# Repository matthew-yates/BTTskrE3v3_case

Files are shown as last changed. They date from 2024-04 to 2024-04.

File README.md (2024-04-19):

These are OpenSCAD design files that can be used for 3D printing a stand alone case for a 3D printer control board (SKR mini E3 V3) and LCD control panel (TFT35 E3 V3).  The control board and LCD panel specs can be found from the manufacturer, Bigtreetech:

http://bttwiki.com/SKR%20MINI%20E3.html

https://bttwiki.com/TFT35%20E3.html

After assembly and programming the microcontroller with Marlin firmware, this case provides a stand alone unit for controlling a 3D printer or CNC machine.

Key features of the case:

* opening for wires required to connect an external power supply, stepper motors, a bed heater, and other optional components on a 3D printer or CNC machine.
* slot to access micro SD card reader used for programming the microcontroller.
* opening for micro USB port that can be used for external control over serial communication from an attached computer.
* slot for accessing the standard SD card and USB-A port that allows control using g-code files.
* mounting points for two 40 mm fans for ventilation.

The image below is a rendering of the bottom part of the case. The "mouse ears" on the box corners aid in keeping the box corners from lifting during printing. The mouse ears can be cut off after printing.

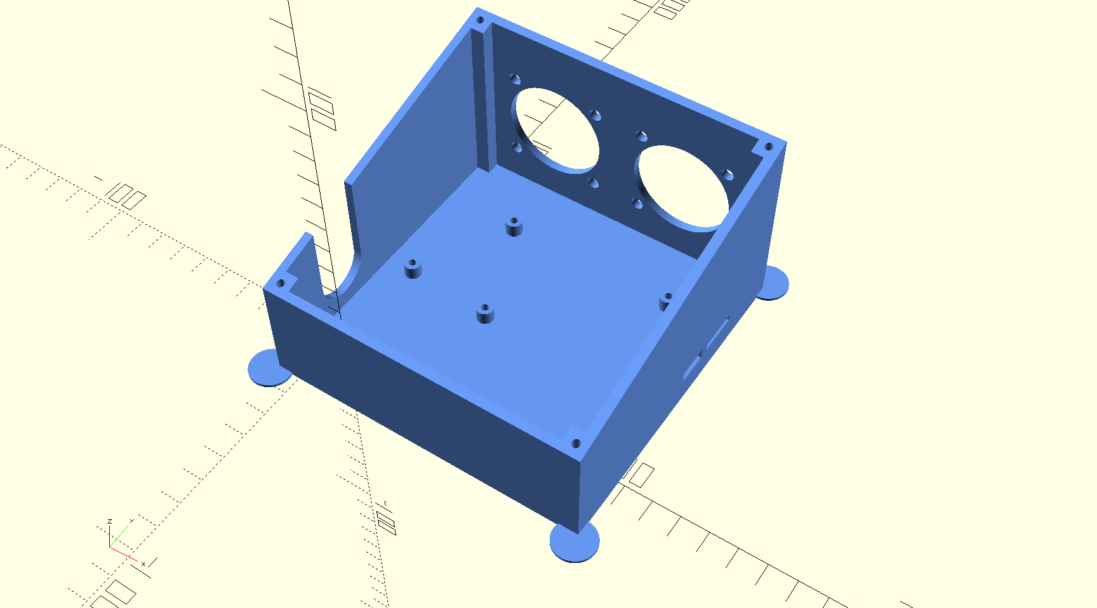
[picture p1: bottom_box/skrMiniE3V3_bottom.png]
bottom box


The image below is a rendering of the top box portion of the case. In addition to the "mouse ears" on the corner to aid in printing, there are thin rectangular supports on each of the four corners that aid in 3D printing.  The mouse ears and supports can be cut off the part after printing.

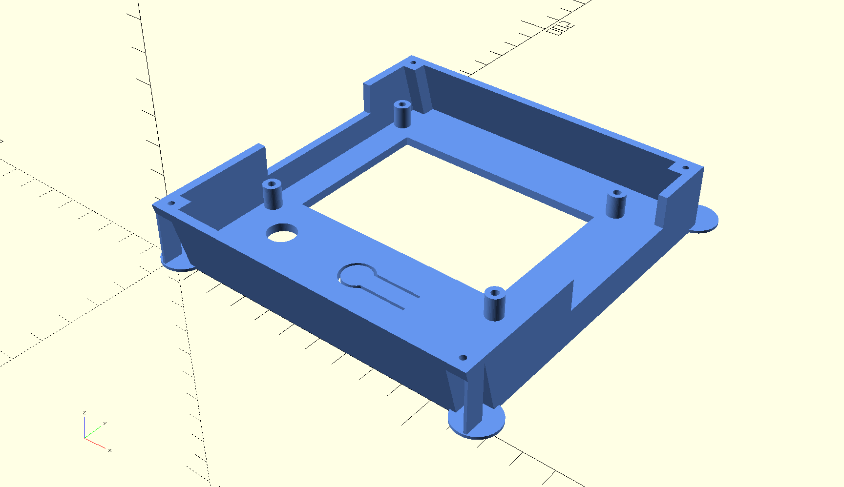
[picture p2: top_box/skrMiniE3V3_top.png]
top box


The image below is a rendering of an exploded view of the completed case after removing printer supports, mounting the TFT35 E3 V3 board to the top portion of the case, and mounting the SKR Mini E3 V3 board to the bottom portion of the case.  The case is colored blue and the Bigtreetech components are colored gray.

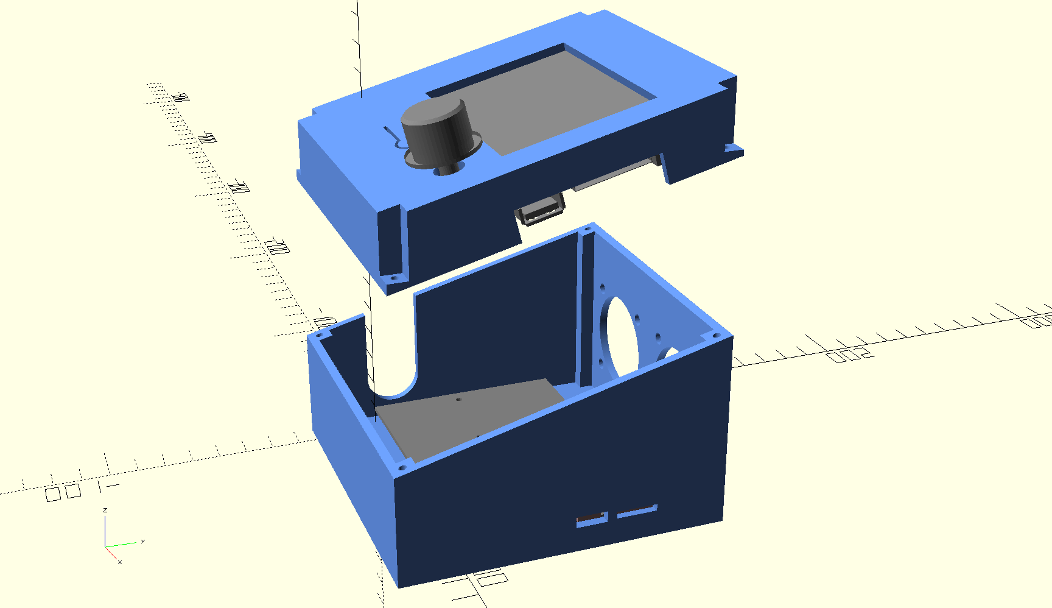
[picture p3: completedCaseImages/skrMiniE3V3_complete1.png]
complete case exploded


The image below is a rendering of the completed case after assembly.  The top part of the case is mounted to the bottom part using M3 screws 8 mm in length.

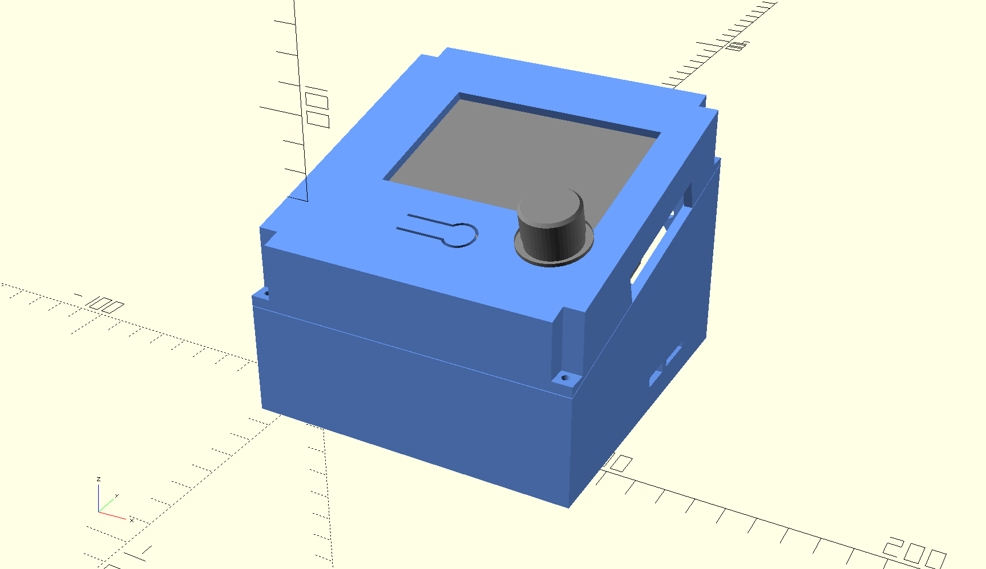
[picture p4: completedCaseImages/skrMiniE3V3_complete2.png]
complete case assembled


For assembly:

* remove printing supports and mouse ears from corners using a sharp blade.
* ream open the four mounting holes on the corners of the top part of the case to allow an M3 screw to pass through.  A 1/8 inch drill bit can be used.
* PCB stand offs as well as the bottom part of the case are printed with holes that allow normal M3 screws to be used (self tapping screws are not needed).
* M3 screws with a pitch of 0.5 mm and length of 8 mm can be used for all PCB mounting holes.
* 40 mm fans must be selected that operate on the same voltage as the external DC power supply.  For most 3D printers, this is 24 Volts.

Below is a photograph of the assembled case with the fans and circuit boards mounted inside:

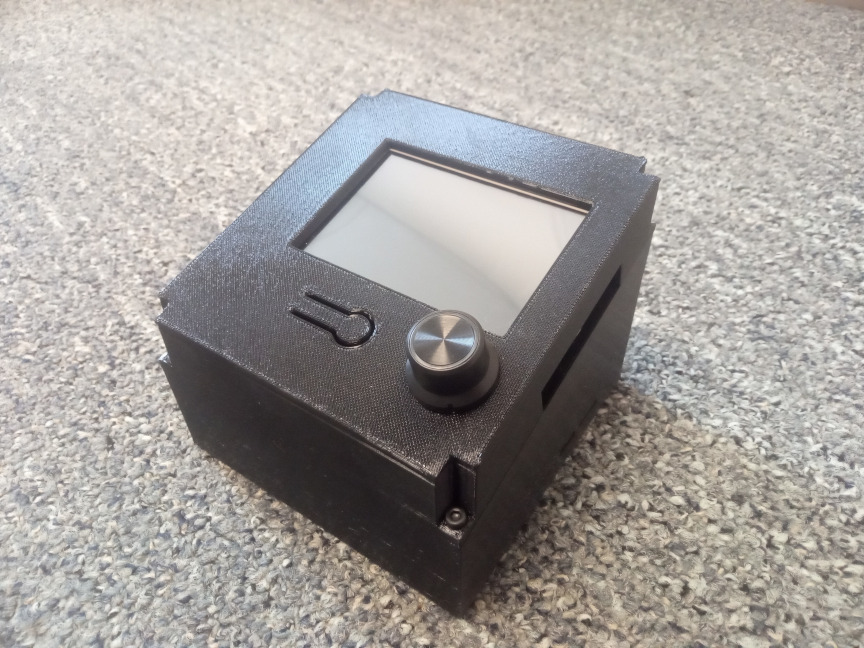
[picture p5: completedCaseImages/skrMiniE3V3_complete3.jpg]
complete case photo


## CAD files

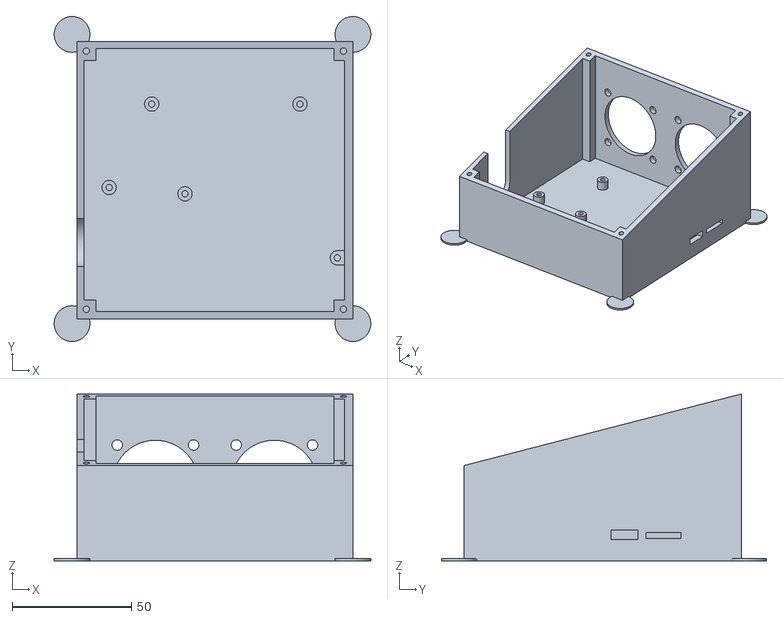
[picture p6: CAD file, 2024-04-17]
bottom_box/skrMiniE3V3_bottom.stl
132.8 x 136.2 x 70.0

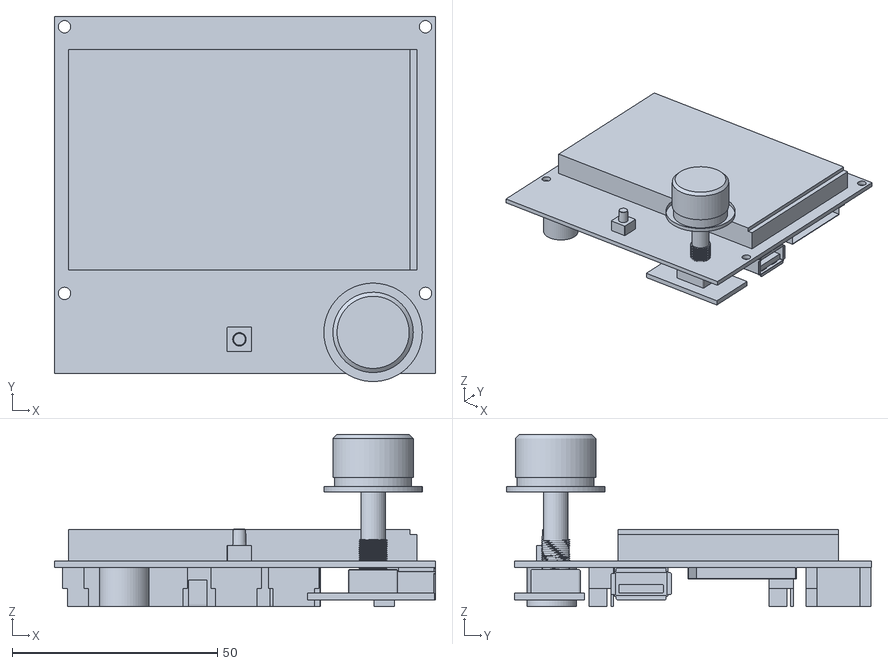
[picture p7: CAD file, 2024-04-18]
top_box/tft35model.stl
93.0 x 89.0 x 42.0

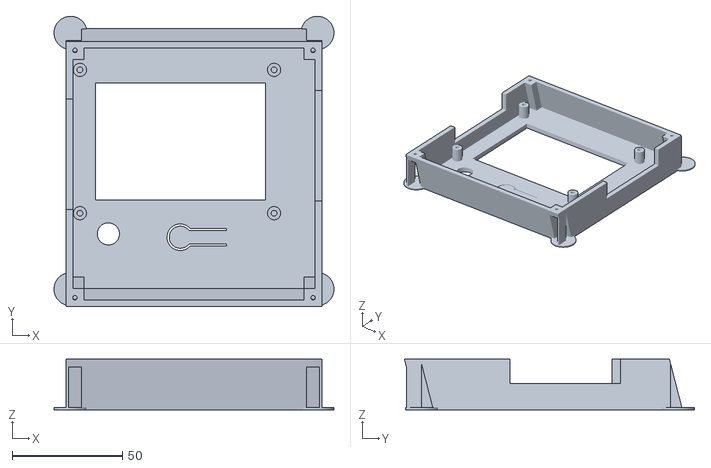
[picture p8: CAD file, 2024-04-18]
top_box/skrMiniE3V3_top.stl
126.8 x 131.4 x 23.0

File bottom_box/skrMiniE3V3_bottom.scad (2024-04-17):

$fa = 1.0;
$fs = 0.4;
// PCB dimensions  ****comment out before generating STL****
// gray is main board with screw hole cut outs
//color("gray"){
//    translate([0,0,8])
//    difference(){
//        cube([103.75,70.25,1.6]);
//        translate([5.54,32.05,-1]) cylinder(h=3,r=1.3);
//        translate([37.34,29.41,-1]) cylinder(h=3,r=1.3);
//        translate([101.22,2.56,-1]) cylinder(h=3,r=1.3);
//        translate([85.55,67.03,-1]) cylinder(h=3,r=1.3);
//        translate([23.40,67.03,-1]) cylinder(h=3,r=1.3);}}
// rosybrown color for surface mount parts on PCB
//color("rosybrown"){
//    // approx shape of SD card reader
//    translate([93.7,53.76,9.6]) cube([11.55,13.7,2]);
//    // approx shape of micro USB port
//    translate([99.5,40,9.6]) cube([5.75,8.38,2]);}
//
//******comment out code above before generating STL********
//
color("cornflowerblue"){
// translate box to leave gaps around PCB
// 5 mm left
// 20 mm front and back
// 0.5 mm right
//
difference(){
//Main box
union(){
   difference(){
        translate([-8,-23,0]) cube([115.75,116.25,70]);
        translate([-5,-20,3]) cube([109.25,110.25,70]);}
    // add corner supports
    translate([-5,-20,0])
    cube([5,5,70]);
    translate([-5,85.25,0])
    cube([5,5,70]);
    translate([99.75,-20,0])
    cube([5,5,70]);
    translate([99.75,85.25,0])
    cube([5,5,70]);
    // add PCB standoffs
    translate([5.54,32.05,0]) cylinder(h=8,r=3);
    translate([37.34,29.41,0]) cylinder(h=8,r=3);
    translate([85.55,67.03,0]) cylinder(h=8,r=3);
    translate([23.40,67.03,0]) cylinder(h=8,r=3);
        hull(){
        translate([101.22,2.56,0]) cylinder(h=8,r=3);
        translate([104,-0.44,0]) cube([2,6,8]);}
    }
 // box cut outs
 //
    // PCB mounting holes for M3 screws
    translate([5.54,32.05,3]) cylinder(h=6,r=1.35);
    translate([37.34,29.41,3]) cylinder(h=6,r=1.35);
    translate([101.22,2.56,3]) cylinder(h=6,r=1.35);
    translate([85.55,67.03,3]) cylinder(h=6,r=1.35);
    translate([23.40,67.03,3]) cylinder(h=6,r=1.35);
    // top lid mounting holes for M3 screws
    translate([-4,-19,32]) cylinder(h=10,r=1.35);
    translate([-4,89.25,61]) cylinder(h=10,r=1.35);
    translate([103.75,-19,32]) cylinder(h=10,r=1.35);
    translate([103.75,89.25,61]) cylinder(h=10,r=1.35);
    // opening for wires
    translate([-7,9,19])
    hull(){
        translate([0,0,35]) cube([5,20,5],center=true);
        rotate([0,90,0])
        cylinder(h=5,r=10,center=true);}
    // cut out for SD card slot
    translate([103.25,53.26,9.5]) cube([5,14.7,2.5]);
    // cut out for micro SD cable
    translate([103.25,38.5,9]) cube([5,11.38,4]);
    // holes for two 40 mm fans
        // large holes for air flow
        // fan 1
    translate([24.94,94.25,32.6]) rotate([90,0,0]) cylinder(h=5,r=18);
        // fan 2
    translate([74.82,94.25,32.6]) rotate([90,0,0]) cylinder(h=5,r=18);
        // small holes for fan 1 screws
    translate([8.94,94.25,48.6]) rotate([90,0,0]) cylinder(h=5,r=2.2);
    translate([40.94,94.25,48.6]) rotate([90,0,0]) cylinder(h=5,r=2.2);
    translate([40.94,94.25,16.6]) rotate([90,0,0]) cylinder(h=5,r=2.2);
    translate([8.94,94.25,16.6]) rotate([90,0,0]) cylinder(h=5,r=2.2);
        // small holes for fan 2 screws
    translate([90.82,94.25,48.6]) rotate([90,0,0]) cylinder(h=5,r=2.2);
    translate([90.82,94.25,16.6]) rotate([90,0,0]) cylinder(h=5,r=2.2);
    translate([58.82,94.25,48.6]) rotate([90,0,0]) cylinder(h=5,r=2.2);
    translate([58.82,94.25,16.6]) rotate([90,0,0]) cylinder(h=5,r=2.2);
    // Top is angled at 14.47 deegrees.  This gives y-axis length 120 mm for lid.
    translate([-8.1,-23.1,40]) rotate([14.47,0,0]) cube([116.75,120.25,70]);
}
// add mouse ears for printing
translate([-10,-25,0]) cylinder(h=1,r=7.5);
translate([107.75,-25,0]) cylinder(h=1,r=7.5);
translate([107.75,96.25,0]) cylinder(h=1,r=7.5);
translate([-10,96.25,0]) cylinder(h=1,r=7.5);}

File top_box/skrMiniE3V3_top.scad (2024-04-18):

$fa = 1.0;
$fs = 0.4;
// PCB dimensions  ****comment out before generating STL****
//color("gray"){
//translate([175.1,-45.6,22.1]) rotate([0,180,0]) import("tft35model.stl");}
//******comment out code above before generating STL********
//
color("cornflowerblue"){
difference(){
union(){
//main plate
cube([115.75,120,3]);
// PCB standoffs
translate([6.23,36.37,0]) cylinder(h=11,r=3);
translate([6.23,101.27,0]) cylinder(h=11,r=3);
translate([94.13,101.27,0]) cylinder(h=11,r=3);
translate([94.13,36.37,0]) cylinder(h=11,r=3);
// left and right sides
translate([0,-5,3]) cube([3,125,20]);
translate([112.75,-5,3]) cube([3,125,20]);
// front and back angled to match bottom box
rotate([14.47,0,0]) cube([115.75,3,25]);
translate([0,117,0]) rotate([14.47,0,0]) cube([115.75,3,25]);
// corner supports and opening for screw tabs
rotate([14.47,0,0]) cube([8,8,25]);
translate([107.75,0,0]) rotate([14.47,0,0]) cube([8,8,25]);
translate([107.75,112,0]) rotate([14.47,0,0]) cube([8,8,25]);
translate([0,112,0]) rotate([14.47,0,0]) cube([8,8,25]);
}
//cut out for LCD panel
translate([13.18,42.32,-1]) cube([77,53,6]);
// holes for M3 PCB mounting screws
translate([6.23,36.37,3]) cylinder(h=9,r=1.35);
translate([6.23,101.27,3]) cylinder(h=9,r=1.35);
translate([94.13,101.27,3]) cylinder(h=9,r=1.35);
translate([94.13,36.37,3]) cylinder(h=9,r=1.35);
// flexible tab for reset button
difference(){
    union(){
        translate([51.67,25.5,-1]) cylinder(h=5,r=6);
        translate([51.67,21.5,-1]) cube([21,8,5]);}
translate([51.67,22.5,-2]) cube([25,6,7]);
translate([51.67,25.5,-2]) cylinder(h=7,r=5);
}
// cut out for knob
translate([19.12,27,-1]) cylinder(h=5,r=5);
// cut out for usb/SD card and venting
translate([-1,38,12]) cube([5,50,23]);
// cut out for venting
translate([111.75,42,12]) cube([5,50,23]);
// cut tabs off front
rotate([14.47,0,0]) translate([-1,-5,0]) cube([117.75,5,25]);
// cut tabs off back
translate([-1,120,0])rotate([14.47,0,0]) cube([117.75,7,25]);
// cut tabs off top
translate([-1,-10,23])  cube([117.75,140,5]);
// cut out for shorter M3 screws
rotate([14.47,0,0]) translate([-1,-1.,-3]) cube([8,8,23]);
rotate([14.47,0,0]) translate([108.75,-1.,-3]) cube([8,8,23]);
translate([108.75,113.,0]) rotate([14.47,0,0]) translate([0,0,-3]) cube([8,8,23]);
translate([-1,113,0]) rotate([14.47,0,0]) translate([0,0,-3]) cube([8,8,23]);
// M3 screw holes for mounting to bottom box
translate([4,4,0]) rotate([14.47,0,0]) translate([0,0,19])  cylinder(5,1.7);
translate([111.75,4,0]) rotate([14.47,0,0]) translate([0,0,19])  cylinder(5,1.7);
translate([4,116,0]) rotate([14.47,0,0]) translate([0,0,19])  cylinder(5,1.7);
translate([111.75,116,0]) rotate([14.47,0,0]) translate([0,0,19])  cylinder(5,1.7);
}
// add corner supports for printing
translate([0,-4.997,0]) cube([1,6.778,22.3]);
translate([114.75,-4.997,0]) cube([1,6.778,22.3]);
translate([0,107.8,0]) cube([1,6.778,21.1]);
translate([114.75,107.8,0]) cube([1,6.778,21.1]);
// add mouse ears for printing
translate([2,2,0]) cylinder(h=1,r=7.5);
translate([113.75,2,0]) cylinder(h=1,r=7.5);
translate([113.75,118,0]) cylinder(h=1,r=7.5);
translate([2,118,0]) cylinder(h=1,r=7.5);
}

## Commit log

2024-04-17 Update skrMiniE3V3_bottom.scad
    Added mouse ears to help hold down box corners while printing.
    [skrMiniE3V3_bottom.scad]
2024-04-17 Update skrMiniE3V3_bottom.scad
    Commented out parts that illustrate PCB board and component sizes.
    [skrMiniE3V3_bottom.scad]
2024-04-17 Add files via upload
    STL file generated by OpenSCAD.
    [skrMiniE3V3_bottom.stl]
2024-04-18 Create skrMiniE3V3_top.scad
    scad code for top box
    [skrMiniE3V3_top.scad]
2024-04-18 Add files via upload
    STL file generated by OpenSCAD
    [skrMiniE3V3_top.stl]
2024-04-18 Update README.md
    added image and description of top portion of the case
2024-04-18 Add files via upload
    model of TFT35 E3 V3 to aid in case design
    [tft35model.stl]
2024-04-18 Update README.md
    added images and description of completed case.
